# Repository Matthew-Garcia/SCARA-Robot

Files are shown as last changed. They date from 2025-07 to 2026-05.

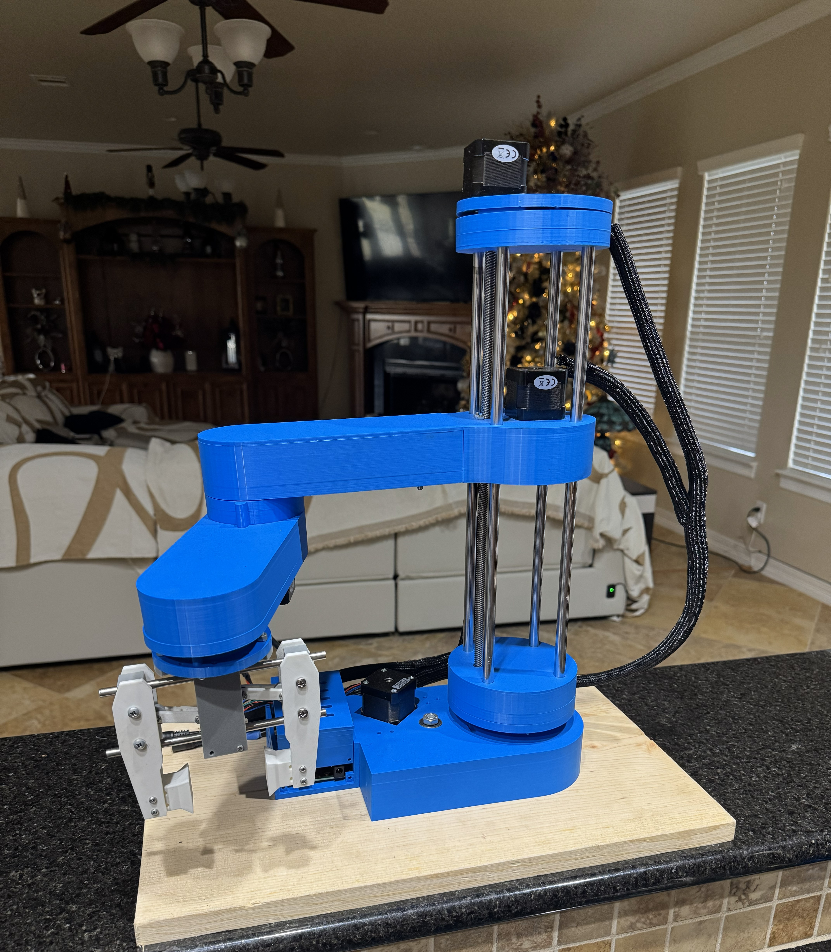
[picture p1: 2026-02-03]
Images/SCARA-Robot-Arm.jpg

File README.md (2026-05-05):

# 🦾 SCARA Robot | Precision 4-DOF Manipulator
**Autonomous Pick-and-Place System | ROS2 & Embedded Control**

A custom-engineered SCARA (Selective Compliance Articulated Robot Arm) designed for high-speed, repeatable automation. This project integrates mechanical design, kinematic theory, and real-time embedded firmware into a functional production prototype.

---

## 🚀 Technical Highlights
* **Kinematic Control:** Implemented **Forward and Inverse Kinematics** for deterministic end-effector positioning in Cartesian space.
* **Motion Planning:** Utilized **PID control** and S-curve acceleration profiles to minimize mechanical jerk and improve repeatability.
* **Digital Twin:** Developed a high-fidelity **URDF model** for simulation in **Gazebo** and visualization in **RViz2**.
* **Embedded Architecture:** Bare-metal firmware (C++) managing stepper motor coordination and real-time sensor feedback.

---

## 🛠 Tech Stack
| Category | Tools & Technologies |
| :--- | :--- |
| **Robotics** | ROS2 (Humble/Foxy), Gazebo, RViz2, MoveIt! |
| **Embedded** | C++, STM32/Arduino, I2C, SPI, AccelStepper |
| **Mechanical** | **SolidWorks**, Bambu Lab X1C (3D Printing), GT2 Pulleys |
| **Control** | Python, Forward/Inverse Kinematics, PID Tuning |

---

## 📸 Media & Performance
### System in Action
SCARA Robot Arm
*Caption: Autonomous pick-and-place cycle demonstrating trajectory repeatability within ±0.5mm.*

---

## 📂 Project Structure
* `/CAD`: SolidWorks assembly files and STL components.
* `/Firmware`: Embedded C++ source code for the microcontroller.
* `/ROS2_WS`: Robot descriptions (URDF), launch files, and simulation nodes.
* `/Scripts`: Python-based GUI and Kinematic solver scripts.

---

## 📈 Future Iterations
- [ ] **Computer Vision:** Integrating OpenCV for autonomous object detection and color sorting.
- [ ] **Structural Rigidity:** Replacing PLA components with Carbon Fiber reinforced filaments for higher payload capacity.
- [ ] **Edge Computing:** Deploying processing nodes on an SBC (Raspberry Pi/Jetson Nano) for decentralized control.

---

### 🔗 Portfolio & Contact
Developed by **Matthew Garcia** [← Back to Portfolio](https://matthew-garcia-portfolio.vercel.app)

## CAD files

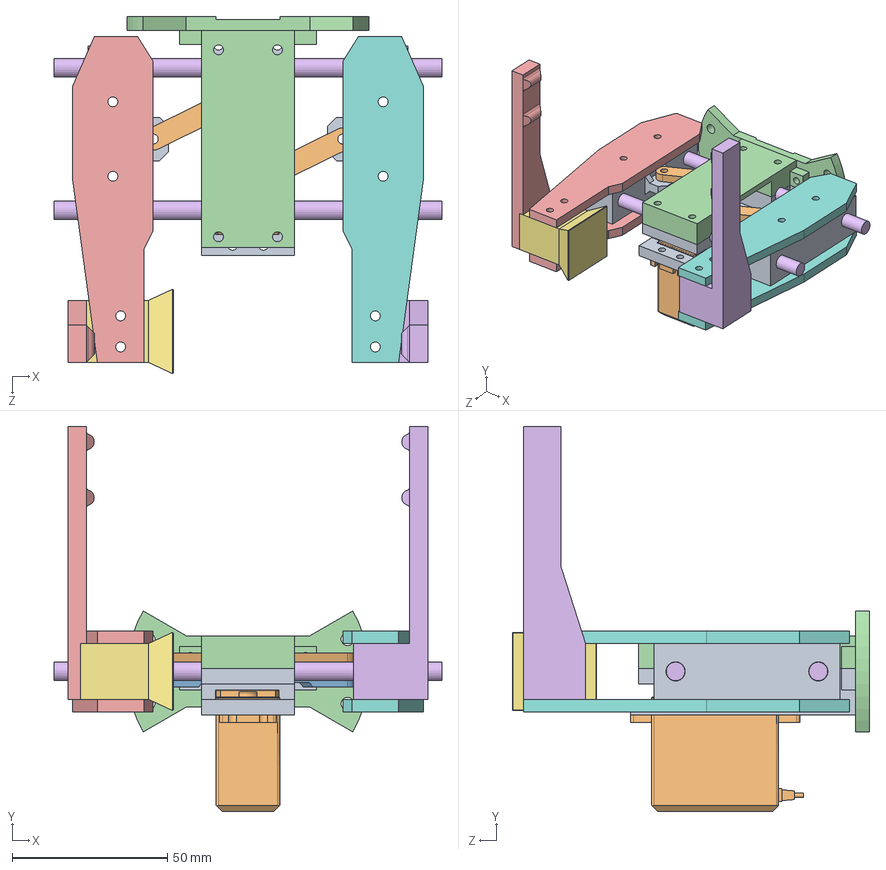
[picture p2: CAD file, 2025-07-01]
3D_Models/Gripper Mechanism.SLDASM
125.0 x 124.2 x 115.1 mm
Servo Holder
Servo Motor MG996R 3D Model
Servo MG996R Horn
Gripper Cover
Gripper Hand Left x 2
Gripper rail 6mm x 2
Gripper Hand Right x 2
Gripper Mechanism Slider x 2
Gripper link 1 x 2
Gripper link 2 x 2
Gripper to J3 connector
Wide gripper end
Wide gripper end - Left side

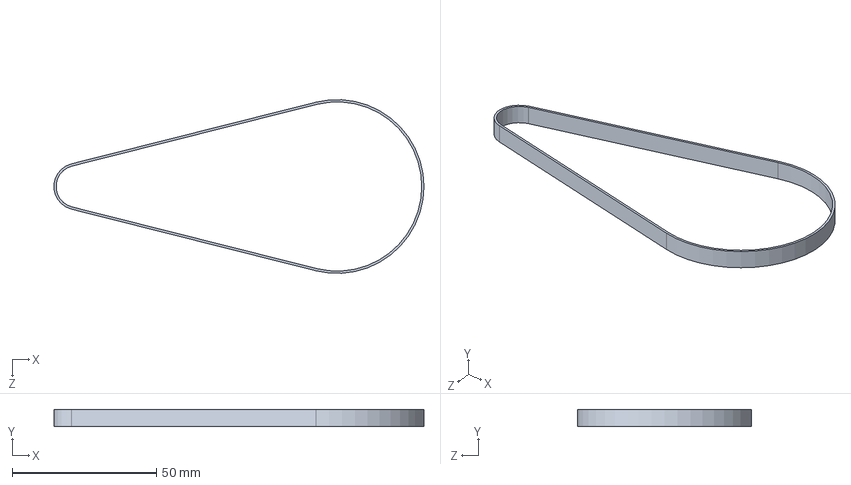
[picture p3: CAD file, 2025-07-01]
3D_Models/GT2 Belt 300mm.SLDPRT
128.1 x 6.00 x 60.1 mm

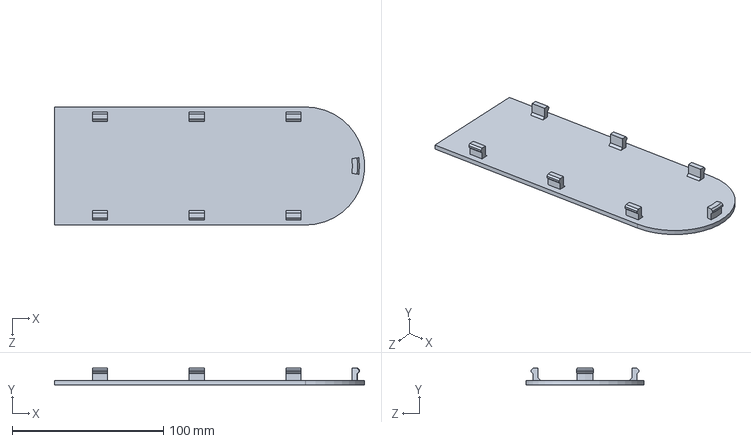
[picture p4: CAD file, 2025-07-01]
3D_Models/Arm 1 Cover.SLDPRT
204.9 x 11.0 x 78.0 mm

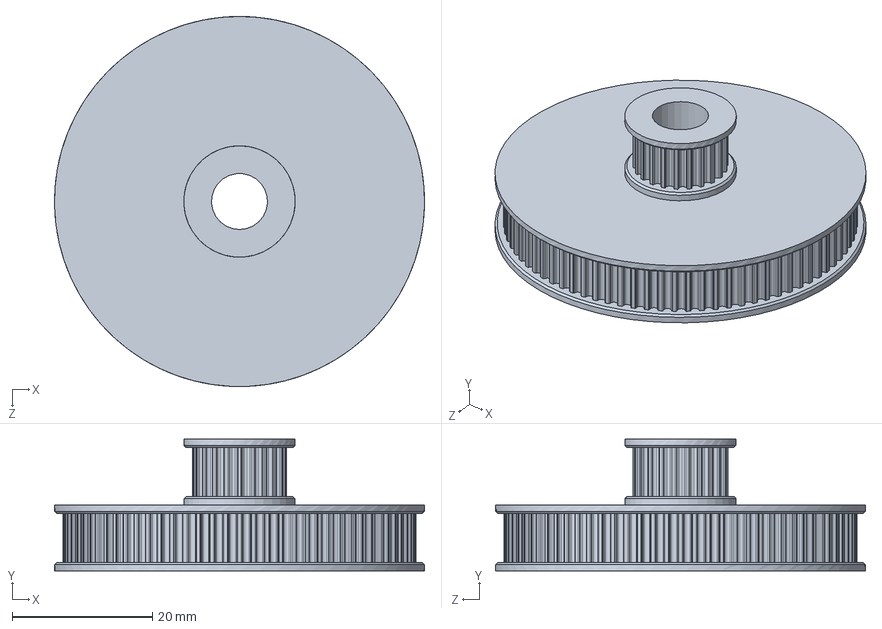
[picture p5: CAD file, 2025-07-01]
3D_Models/GT2 Pulley - 22 - 80 teeth.SLDPRT
52.8 x 18.8 x 52.8 mm

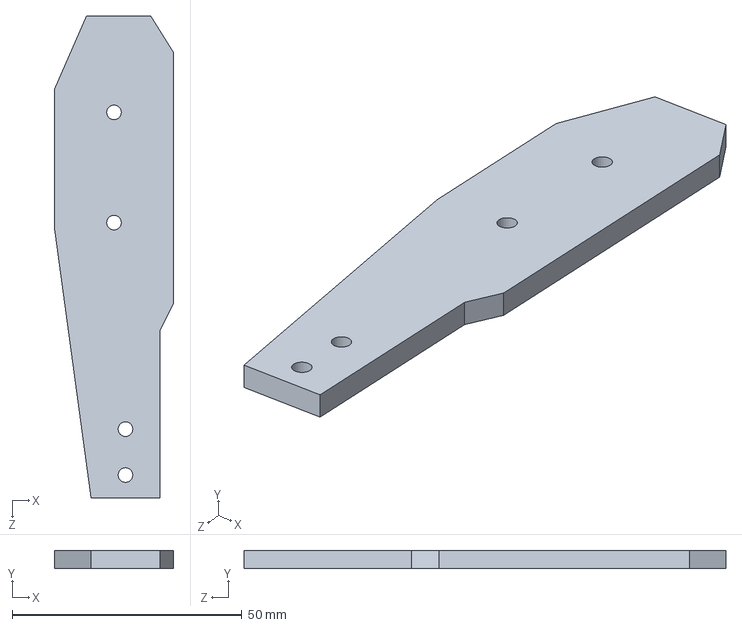
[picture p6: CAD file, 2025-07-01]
3D_Models/Gripper Hand Left.SLDPRT
26.0 x 4.00 x 105.0 mm

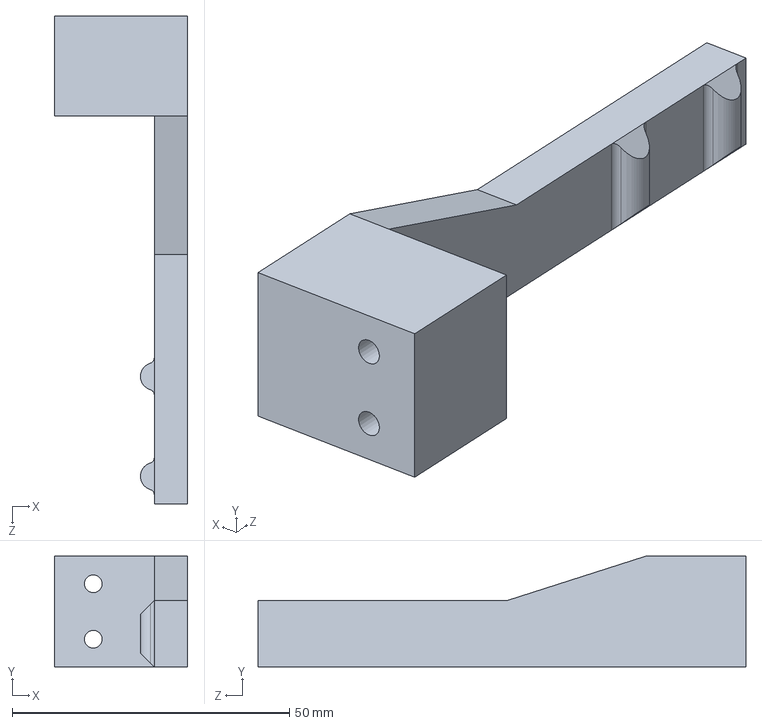
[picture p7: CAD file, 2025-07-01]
3D_Models/Wide gripper end - Left side.SLDPRT
24.0 x 20.0 x 88.0 mm

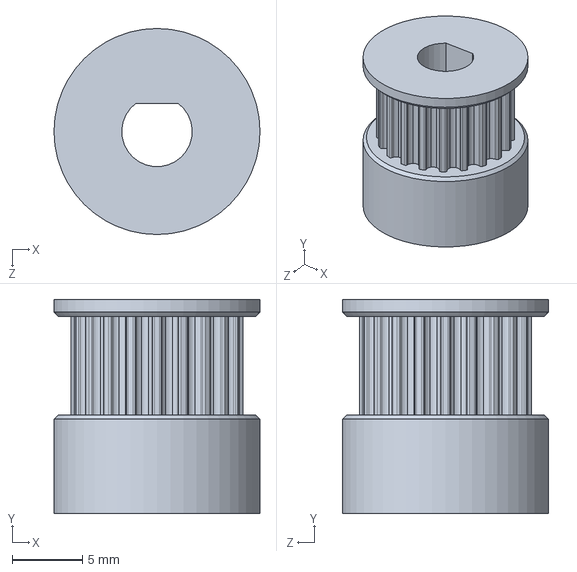
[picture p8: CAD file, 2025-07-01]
3D_Models/GT2 Pulley - Parametric.SLDPRT
14.6 x 15.2 x 14.6 mm

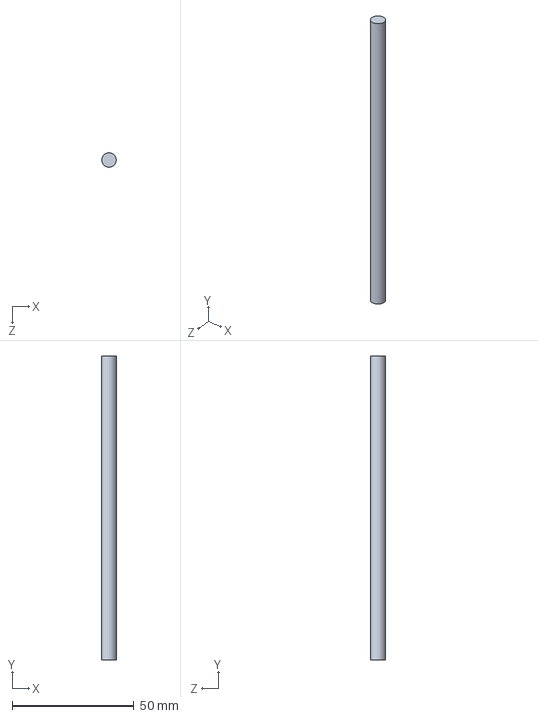
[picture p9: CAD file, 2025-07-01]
3D_Models/Gripper rail 6mm.SLDPRT
6.00 x 125.0 x 6.00 mm

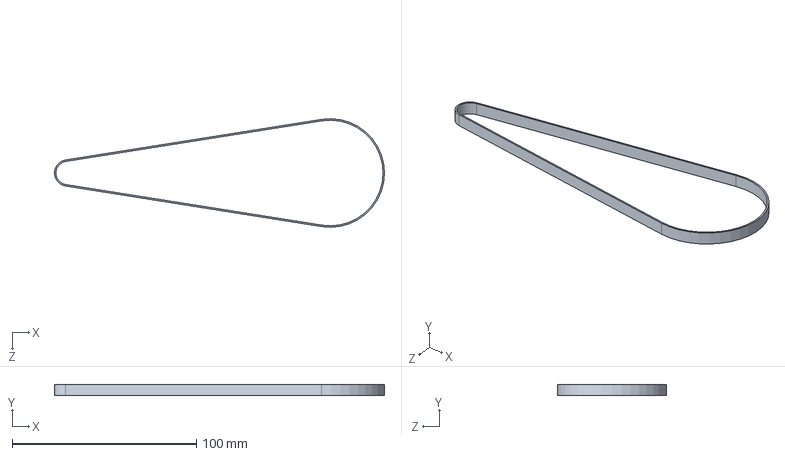
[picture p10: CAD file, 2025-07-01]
3D_Models/GT2 Belt 400mm 2.SLDPRT
179.0 x 6.00 x 58.9 mm

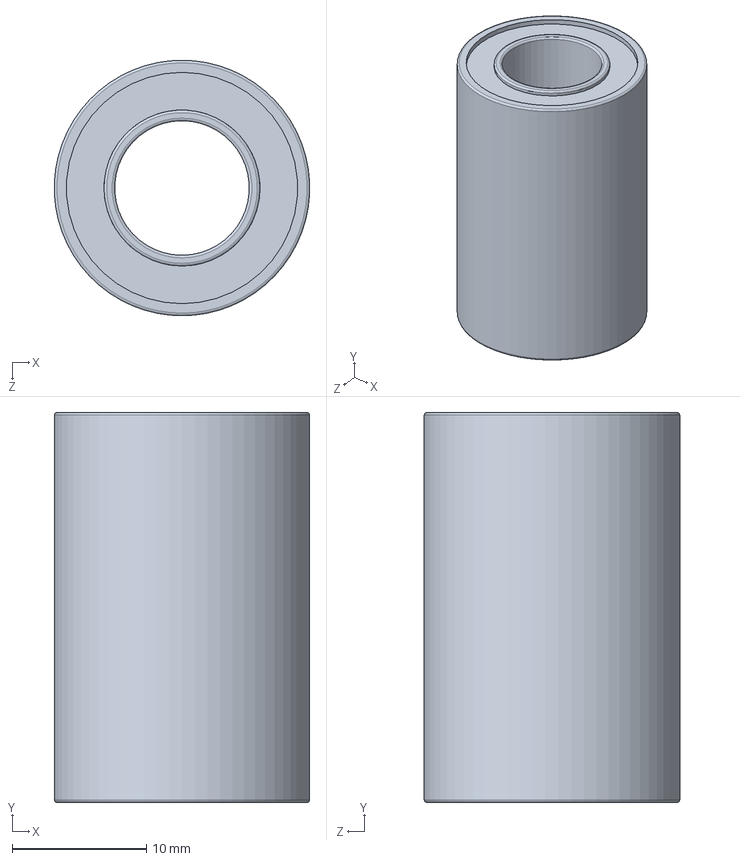
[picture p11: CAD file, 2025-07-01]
3D_Models/Linear Bearing 10x19x29mm.SLDPRT
19.0 x 29.0 x 19.0 mm

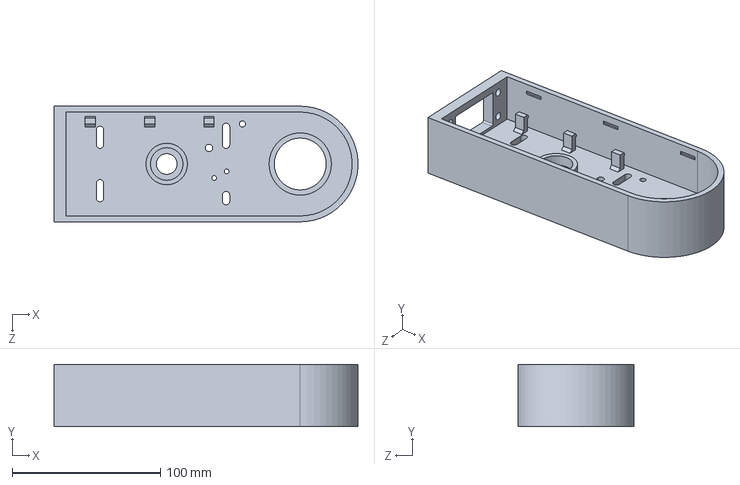
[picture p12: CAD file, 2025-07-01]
3D_Models/Arm 1.SLDPRT
204.9 x 42.0 x 78.0 mm

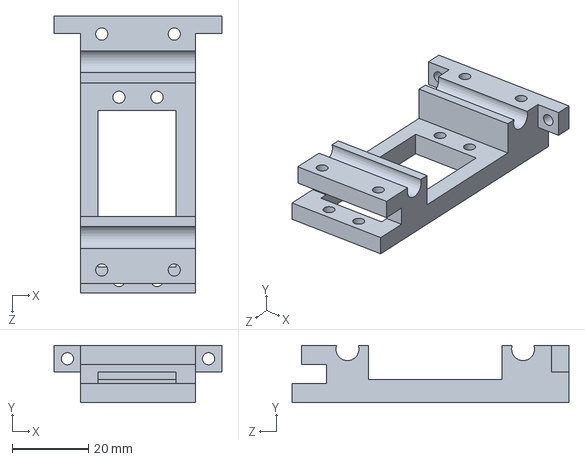
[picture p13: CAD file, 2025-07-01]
3D_Models/Servo Holder.SLDPRT
44.0 x 15.0 x 72.5 mm

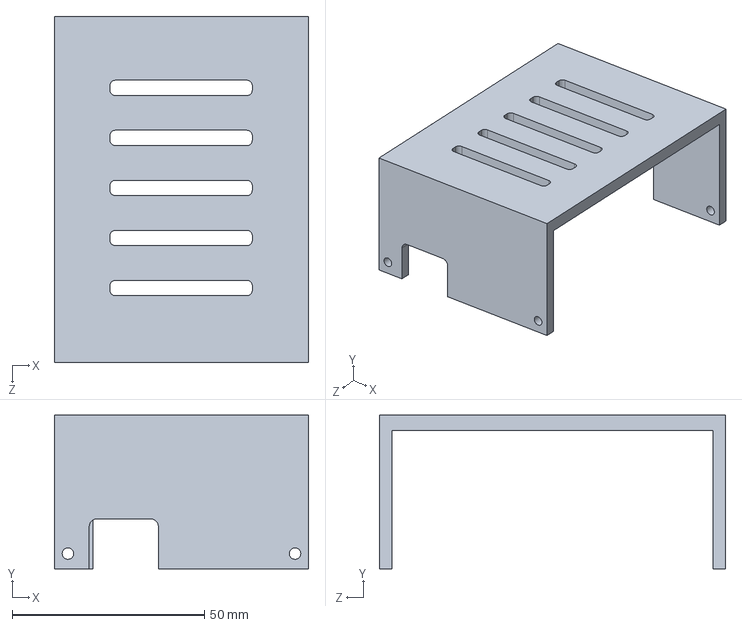
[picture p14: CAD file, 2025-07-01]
3D_Models/Arduino UNO case p2.SLDPRT
66.0 x 40.0 x 90.0 mm

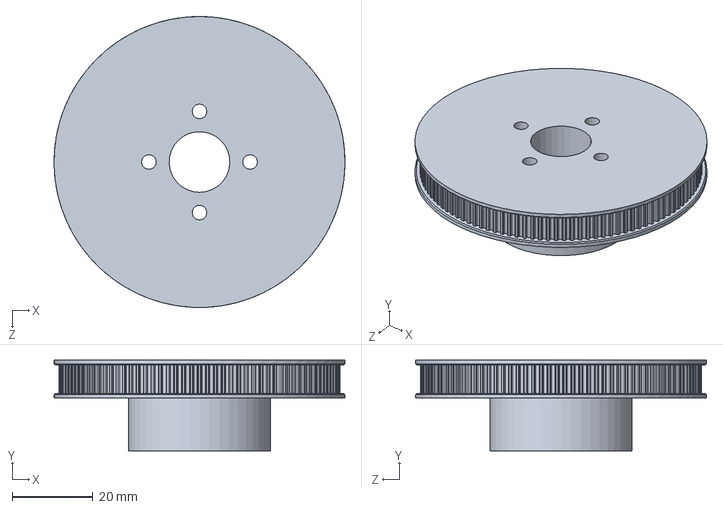
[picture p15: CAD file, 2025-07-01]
3D_Models/GT2 Pulley - 110 teeth - J1.SLDPRT
71.9 x 22.4 x 71.9 mm

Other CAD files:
3D_Models/Ball Bearing 35x47x7mm.SLDPRT
3D_Models/Arm 2 Cover.SLDPRT
3D_Models/Z-axis Top Plate.SLDPRT
3D_Models/Thrust Bearing - 40x60x13.SLDPRT
3D_Models/Arduino UNO case p1.SLDPRT
3D_Models/Arm 2.SLDPRT
3D_Models/Ball Bearing 30x42x7mm.SLDPRT
3D_Models/Ball Bearing 608 - 8x22x7mm.SLDPRT
3D_Models/Base cover.SLDPRT
3D_Models/Base.SLDPRT
3D_Models/GT2 Belt 200mm.SLDPRT
3D_Models/GT2 Belt 300mm 2.SLDPRT
3D_Models/GT2 Belt 400mm.SLDPRT
3D_Models/GT2 Pulley - 23 - 80 teeth.SLDPRT
3D_Models/GT2 Pulley - 90 teeth - J3.SLDPRT
3D_Models/GT2 Pulley - 92 teeth - J2.SLDPRT
3D_Models/Gripper Cover.SLDPRT
3D_Models/Gripper End.SLDPRT
3D_Models/Gripper Hand Right.SLDPRT
3D_Models/Gripper Mechanism Slider.SLDPRT
3D_Models/Gripper link 1.SLDPRT
3D_Models/Gripper link 2.SLDPRT
3D_Models/Gripper to J3 connector.SLDPRT
3D_Models/J1 coupler.SLDPRT
3D_Models/J2 Coupler.SLDPRT
3D_Models/J3 Coupler.SLDPRT
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

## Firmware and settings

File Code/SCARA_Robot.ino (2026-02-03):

/* 
   Title     : SCARA Robot (Arduino-based)
   Author    : Matthew Garcia
   Date      : November 26, 2025
   Objective : Implement a GUI-controlled SCARA robot controller that supports manual slider motion, 
               recording waypoints, and smooth looping playback using AccelStepper, with gripper control 
               and a safe STOP return to the last manual position.
*/

#include <AccelStepper.h>
#include <Servo.h>

// -------------------------------
//  STEP/DIR → CNC Shield Mapping
// -------------------------------
AccelStepper stepper1(1, 2, 5);   // J1
AccelStepper stepper2(1, 3, 6);   // J2
AccelStepper stepper3(1, 4, 7);   // J3
AccelStepper stepper4(1, 12, 13); // Z

Servo gripperServo;

// Angle → steps conversion
const float theta1AngleToSteps = 44.444444f;
const float theta2AngleToSteps = 35.555555f;
const float phiAngleToSteps    = 10.0f;
const float zDistanceToSteps   = 100.0f;

String content = "";
int data[10];

// Stored program arrays
int theta1Array[100];
int theta2Array[100];
int phiArray[100];
int zArray[100];
int gripperArray[100];
int positionsCounter = 0;

// Manual backup for STOP return
int manualJ1_backup = 0;
int manualJ2_backup = 0;
int manualJ3_backup = 0;
int manualZ_backup  = 0;

// Flags
bool ignoreManualUpdates = false;
bool saveManualPos = true;
bool firstSyncFromGUI = false;

// ---------------------------------
void homing() {
  stepper1.setCurrentPosition(0);
  stepper2.setCurrentPosition(0);
  stepper3.setCurrentPosition(0);
  stepper4.setCurrentPosition(0);
}
// ---------------------------------

void setup() {
  Serial.begin(115200);

  // Default motion limits
  stepper1.setMaxSpeed(4000);
  stepper1.setAcceleration(2000);

  stepper2.setMaxSpeed(4000);
  stepper2.setAcceleration(2000);

  stepper3.setMaxSpeed(4000);
  stepper3.setAcceleration(2000);

  stepper4.setMaxSpeed(4000);
  stepper4.setAcceleration(2000);

  // Fix Z direction
  stepper4.setPinsInverted(false, true);

  gripperServo.attach(A0, 600, 2500);
  gripperServo.write(180);
  delay(600);

  homing();
}

// ---------------------------------
void loop() {

  // ---------------------------------------
  // RECEIVE GUI PACKET
  // ---------------------------------------
  if (Serial.available()) {
    content = Serial.readString();

    for (int i = 0; i < 10; i++) {
      int index = content.indexOf(",");
      data[i] = atol(content.substring(0, index).c_str());
      content = content.substring(index + 1);
    }

    // Save a point
    if (data[0] == 1) {
      theta1Array[positionsCounter] = data[2] * theta1AngleToSteps;
      theta2Array[positionsCounter] = data[3] * theta2AngleToSteps;
      phiArray[positionsCounter]    = data[4] * phiAngleToSteps;
      zArray[positionsCounter]      = data[5] * zDistanceToSteps;
      gripperArray[positionsCounter] = data[6];
      positionsCounter++;
    }

    // Clear stored program
    if (data[0] == 2) {
      memset(theta1Array, 0, sizeof(theta1Array));
      memset(theta2Array, 0, sizeof(theta2Array));
      memset(phiArray, 0, sizeof(phiArray));
      memset(zArray, 0, sizeof(zArray));
      memset(gripperArray, 0, sizeof(gripperArray));
      positionsCounter = 0;
    }
  }

  // ---------------------------------------
  // RUN PROGRAM MODE
  // ---------------------------------------
  if (data[1] == 1) {

    ignoreManualUpdates = true;

    // Backup manual pose once
    if (saveManualPos) {
      manualJ1_backup = stepper1.currentPosition();
      manualJ2_backup = stepper2.currentPosition();
      manualJ3_backup = stepper3.currentPosition();
      manualZ_backup  = stepper4.currentPosition();
      saveManualPos = false;
    }

    // Apply speed/accel = maxSpeed
    stepper1.setMaxSpeed(data[7]);
    stepper2.setMaxSpeed(data[7]);
    stepper3.setMaxSpeed(data[7]);
    stepper4.setMaxSpeed(data[7]);

    stepper1.setAcceleration(data[8]);
    stepper2.setAcceleration(data[8]);
    stepper3.setAcceleration(data[8]);
    stepper4.setAcceleration(data[8]);

    // Loop through stored steps
    for (int i = 0; i < positionsCounter; i++) {

      // Break if STOP pressed
      if (data[1] == 0) break;

      stepper1.moveTo(theta1Array[i]);
      stepper2.moveTo(theta2Array[i]);
      stepper3.moveTo(phiArray[i]);
      stepper4.moveTo(zArray[i]);

      // Smooth motion to target
      while (stepper1.distanceToGo() != 0 ||
             stepper2.distanceToGo() != 0 ||
             stepper3.distanceToGo() != 0 ||
             stepper4.distanceToGo() != 0) {

        stepper1.run();
        stepper2.run();
        stepper3.run();
        stepper4.run();

        // LIVE STOP CHECK
        if (Serial.available()) {
          content = Serial.readString();
          int index = content.indexOf(",");
          data[1] = atol(content.substring(index + 1).c_str());
          if (data[1] == 0) break;
        }
      }

      if (data[1] == 0) break;

      // Gripper update
      if (i == 0 || gripperArray[i] != gripperArray[i - 1]) {
        gripperServo.write(gripperArray[i]);
        delay(300);
      }

      // Dwell time (smooth, robot-like)
      delay(300);   // <<< NEW
    }
  }

  // ---------------------------------------
  // STOP → return to manual position
  // ---------------------------------------
  if (data[1] == 0 && ignoreManualUpdates) {

    ignoreManualUpdates = false;

    stepper1.moveTo(manualJ1_backup);
    stepper2.moveTo(manualJ2_backup);
    stepper3.moveTo(manualJ3_backup);
    stepper4.moveTo(manualZ_backup);

    while (stepper1.distanceToGo() != 0 ||
           stepper2.distanceToGo() != 0 ||
           stepper3.distanceToGo() != 0 ||
           stepper4.distanceToGo() != 0) {

      stepper1.run();
      stepper2.run();
      stepper3.run();
      stepper4.run();
    }

    saveManualPos = true;
  }

  // ---------------------------------------
  // MANUAL SLIDER CONTROL
  // ---------------------------------------
  if (!ignoreManualUpdates) {

    int j1Steps = data[2] * theta1AngleToSteps;
    int j2Steps = data[3] * theta2AngleToSteps;
    int j3Steps = data[4] * phiAngleToSteps;
    int zSteps  = data[5] * zDistanceToSteps;

    if (!firstSyncFromGUI) {
      stepper1.setCurrentPosition(j1Steps);
      stepper2.setCurrentPosition(j2Steps);
      stepper3.setCurrentPosition(j3Steps);
      stepper4.setCurrentPosition(zSteps);
      firstSyncFromGUI = true;
    } else {
      stepper1.moveTo(j1Steps);
      stepper2.moveTo(j2Steps);
      stepper3.moveTo(j3Steps);
      stepper4.moveTo(zSteps);

      while (stepper1.distanceToGo() != 0 ||
             stepper2.distanceToGo() != 0 ||
             stepper3.distanceToGo() != 0 ||
             stepper4.distanceToGo() != 0) {

        stepper1.run();
        stepper2.run();
        stepper3.run();
        stepper4.run();
      }
    }

    gripperServo.write(data[6]);
    delay(200);
  }
}

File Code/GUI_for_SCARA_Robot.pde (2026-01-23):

/*
   Title   : SCARA Robot GUI (Arduino-based)
   Author  : Matthew Garcia
   Date    : June 3, 2025
   Purpose : Implements a graphical user interface to control a SCARA robot using Arduino.
             Utilizes the AccelStepper library for stepper motor control.
             Library reference: http://www.airspayce.com/mikem/arduino/AccelStepper/
*/

import processing.serial.*;
import controlP5.*; 
import static processing.core.PApplet.*;

Serial myPort;
ControlP5 cp5; // controlP5 object

int j1Slider = 0;
int j2Slider = 0;
int j3Slider = 0;
int zSlider = 0;
int j1JogValue = 0;
int j2JogValue = 0;
int j3JogValue = 0;
int zJogValue = 0;
int speedSlider = 500;
int accelerationSlider = 500;
int gripperValue = 180;
int gripperAdd=180;
int positionsCounter = 0;


int saveStatus = 0;
int runStatus = 0;

int slider1Previous = 0;
int slider2Previous = 0;
int slider3Previous = 0;
int sliderzPrevious = 100;
int speedSliderPrevious = 500;
int accelerationSliderPrevious = 500;
int gripperValuePrevious = 100;

boolean activeIK = false;

int xP=365;
int yP=0;
int zP=100;
float L1 = 228; // L1 = 228mm
float L2 = 136.5; // L2 = 136.5mm
float theta1, theta2, phi, z;

String[] positions = new String[100];

String data;

void setup() {

  size(960, 800);
  myPort = new Serial(this, "COM4", 115200);
  
  cp5 = new ControlP5(this);

  PFont pfont = createFont("Arial", 25, true); // use true/false for smooth/no-smooth
  ControlFont font = new ControlFont(pfont, 22);
  ControlFont font2 = new ControlFont(pfont, 25);

  //J1 controls
  cp5.addSlider("j1Slider")
    .setPosition(110, 190)
    .setSize(270, 30)
    .setRange(-90, 266) // Slider range, corresponds to Joint 1 or theta1 angle that the robot can move to
    .setColorLabel(#3269c2)
    .setFont(font)
    .setCaptionLabel("")
    ;
  cp5.addButton("j1JogMinus")
    .setPosition(110, 238)
    .setSize(90, 40)
    .setFont(font)
    .setCaptionLabel("JOG-")
    ;
  cp5.addButton("j1JogPlus")
    .setPosition(290, 238)
    .setSize(90, 40)
    .setFont(font)
    .setCaptionLabel("JOG+")
    ;
  cp5.addNumberbox("j1JogValue")
    .setPosition(220, 243)
    .setSize(50, 30)
    .setRange(0, 20)
    .setFont(font)
    .setMultiplier(0.1)
    .setValue(1)
    .setDirection(Controller.HORIZONTAL) // change the control direction to left/right
    .setCaptionLabel("")
    ;

  //J2 controls
  cp5.addSlider("j2Slider")
    .setPosition(110, 315)
    .setSize(270, 30)
    .setRange(-150, 150)
    .setColorLabel(#3269c2)
    .setFont(font)
    .setCaptionLabel("")
    ;
  cp5.addButton("j2JogMinus")
    .setPosition(110, 363)
    .setSize(90, 40)
    .setFont(font)
    .setCaptionLabel("JOG-")
    ;
  cp5.addButton("j2JogPlus")
    .setPosition(290, 363)
    .setSize(90, 40)
    .setFont(font)
    .setCaptionLabel("JOG+")
    ;
  cp5.addNumberbox("j2JogValue")
    .setPosition(220, 368)
    .setSize(50, 30)
    .setRange(0, 20)
    .setFont(font)
    .setMultiplier(0.1)
    .setValue(1)
    .setDirection(Controller.HORIZONTAL) // change the control direction to left/right
    .setCaptionLabel("")
    ;
  //J3 controls
  cp5.addSlider("j3Slider")
    .setPosition(110, 440)
    .setSize(270, 30)
    .setRange(-162, 162)
    .setColorLabel(#3269c2)
    .setFont(font)
    .setCaptionLabel("")
    ;
  cp5.addButton("j3JogMinus")
    .setPosition(110, 493)
    .setSize(90, 40)
    .setFont(font)
    .setCaptionLabel("JOG-")
    ;
  cp5.addButton("j3JogPlus")
    .setPosition(290, 493)
    .setSize(90, 40)
    .setFont(font)
    .setCaptionLabel("JOG+")
    ;
  cp5.addNumberbox("j3JogValue")
    .setPosition(220, 493)
    .setSize(50, 30)
    .setRange(0, 20)
    .setFont(font)
    .setMultiplier(0.1)
    .setValue(1)
    .setDirection(Controller.HORIZONTAL) // change the control direction to left/right
    .setCaptionLabel("")
    ;

  //Z controls
  cp5.addSlider("zSlider")
    .setPosition(110, 565)
    .setSize(270, 30)
    .setRange(-50, 50)
    .setColorLabel(#3269c2)
    .setFont(font)
    .setCaptionLabel("")
    ;
  cp5.addButton("zJogMinus")
    .setPosition(110, 618)
    .setSize(90, 40)
    .setFont(font)
    .setCaptionLabel("JOG-")
    ;
  cp5.addButton("zJogPlus")
    .setPosition(290, 618)
    .setSize(90, 40)
    .setFont(font)
    .setCaptionLabel("JOG+")
    ;
  cp5.addNumberbox("zJogValue")
    .setPosition(220, 618)
    .setSize(50, 30)
    .setRange(0, 20)
    .setFont(font)
    .setMultiplier(0.1)
    .setValue(1)
    .setDirection(Controller.HORIZONTAL) // change the control direction to left/right
    .setCaptionLabel("")
    ;


  cp5.addTextfield("xTextfield")
    .setPosition(530, 205)
    .setSize(70, 40)
    .setFont(font)
    .setColor(255)
    .setCaptionLabel("")
    ;
  cp5.addTextfield("yTextfield")
    .setPosition(680, 205)
    .setSize(70, 40)
    .setFont(font)
    .setColor(255)
    .setCaptionLabel("")
    ;
  cp5.addTextfield("zTextfield")
    .setPosition(830, 205)
    .setSize(70, 40)
    .setFont(font)
    .setColor(255)
    .setCaptionLabel("")
    ;

  cp5.addButton("move")
    .setPosition(590, 315)
    .setSize(240, 45)
    .setFont(font)
    .setCaptionLabel("MOVE TO POSITION")
    ;

  cp5.addButton("savePosition")
    .setPosition(470, 520)
    .setSize(215, 50)
    .setFont(font2)
    .setCaptionLabel("SAVE POSITION")
    ;

  cp5.addButton("run")
    .setPosition(725, 520)
    .setSize(215, 50)
    .setFont(font2)
    .setCaptionLabel("RUN PROGRAM")
    ;

  cp5.addButton("updateSA")
    .setPosition(760, 590)
    .setSize(150, 40)
    .setFont(font)
    .setCaptionLabel("(Update)")
    ;

  cp5.addButton("clearSteps")
    .setPosition(490, 650)
    .setSize(135, 40)
    .setFont(font)
    .setCaptionLabel("(CLEAR)")
    ;

  //Z controls
  cp5.addSlider("speedSlider")
    .setPosition(490, 740)
    .setSize(180, 30)
    .setRange(500, 4000)
    .setColorLabel(#3269c2)
    .setFont(font)
    .setCaptionLabel("")
    ;

  cp5.addSlider("accelerationSlider")
    .setPosition(720, 740)
    .setSize(180, 30)
    .setRange(500, 4000)
    .setColorLabel(#3269c2)
    .setFont(font)
    .setCaptionLabel("")
    ;
  cp5.addSlider("gripperValue")
    .setPosition(605, 445)
    .setSize(190, 30)
    .setRange(0, 180)            // 0, 100 <- prev range values
    .setColorLabel(#3269c2)
    .setFont(font)
    .setCaptionLabel("")
    ;
}
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
